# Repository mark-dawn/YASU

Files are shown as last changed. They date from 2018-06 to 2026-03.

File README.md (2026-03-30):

# YASU

## What's this?
__Yet Another Saturn__ to __USB__ is a small pet project with 3 aims:
1. Connect a couple of Saturn controllers to my PC for retrogaming
2. Learn how the USB protocol works
3. Learn how to make a PCB and other hardware shenanigans

While I do not expect it to blow anyone's mind, I believe that the code and board turned out quite good
and are usable both in practice and for learning purposes.

## Hardware support
For now only the standard Saturn controller is supported, and has been tested with Japanese `HSS-0101` controllers.

However the code is structured so it should be easy to add support for other Saturn peripherals;
for sure, support for the _3D Controller_ is planned since I own one of those.

Support for the Saturn Mouse might be harder since the board should reconfigure itself as a pointer HID device at enumeration time.

## Note about contacts
The connection between board and the Saturn plug is handled quite rudimentary at the moment.
Flat naked metal pads on tabs that fit inside the cavity of the plug are present,
but cannot make direct contact with the pads in the plug.

For now the "intended" way is to solder extension metal pads to make contact,
but it is quite hard to solder those manually and the connection can act shaky.

In the future I plan to swap those out for flat pogo pins, or if no suitable part exists, use a proper 3D printed receptacle.

## Credits
This project would have not been as easy as it was without various resources from the Internets.
* Objective development for the excellent [v-usb library](https://github.com/obdev/v-usb)
* [Raphaël Assénat](http://www.raphnet.net/index_en), that has a similar [project](http://www.raphnet.net/electronique/saturn_usb/index_en.php) with excellent documentation
* https://gamesx.com/controldata/saturn.htm for a starting point on how to read the standard controller
* Any kind soul that has written small tutorials for ~~messy sintax~~ makefiles

## TODO
* Fix contact between board and Saturn Plug
* Add support for 3D pad
* Extend credits list, expecially for HID configuration examples
* Look into how licenses work since v-usb is under the GPL-2, and go around and slap it in the files that necessitate it
* Add better documentation to `Saturn.c` to clarify which bits are getting extracted without having to look at the header file

## License
All the repository is licensed under the GPL-3. See `LICENSE` for more info.

    Copyright (C) 2022  Marica Albanesi

    This program is free software: you can redistribute it and/or modify
    it under the terms of the GNU General Public License as published by
    the Free Software Foundation, either version 3 of the License, or
    (at your option) any later version.

    This program is distributed in the hope that it will be useful,
    but WITHOUT ANY WARRANTY; without even the implied warranty of
    MERCHANTABILITY or FITNESS FOR A PARTICULAR PURPOSE.  See the
    GNU General Public License for more details.

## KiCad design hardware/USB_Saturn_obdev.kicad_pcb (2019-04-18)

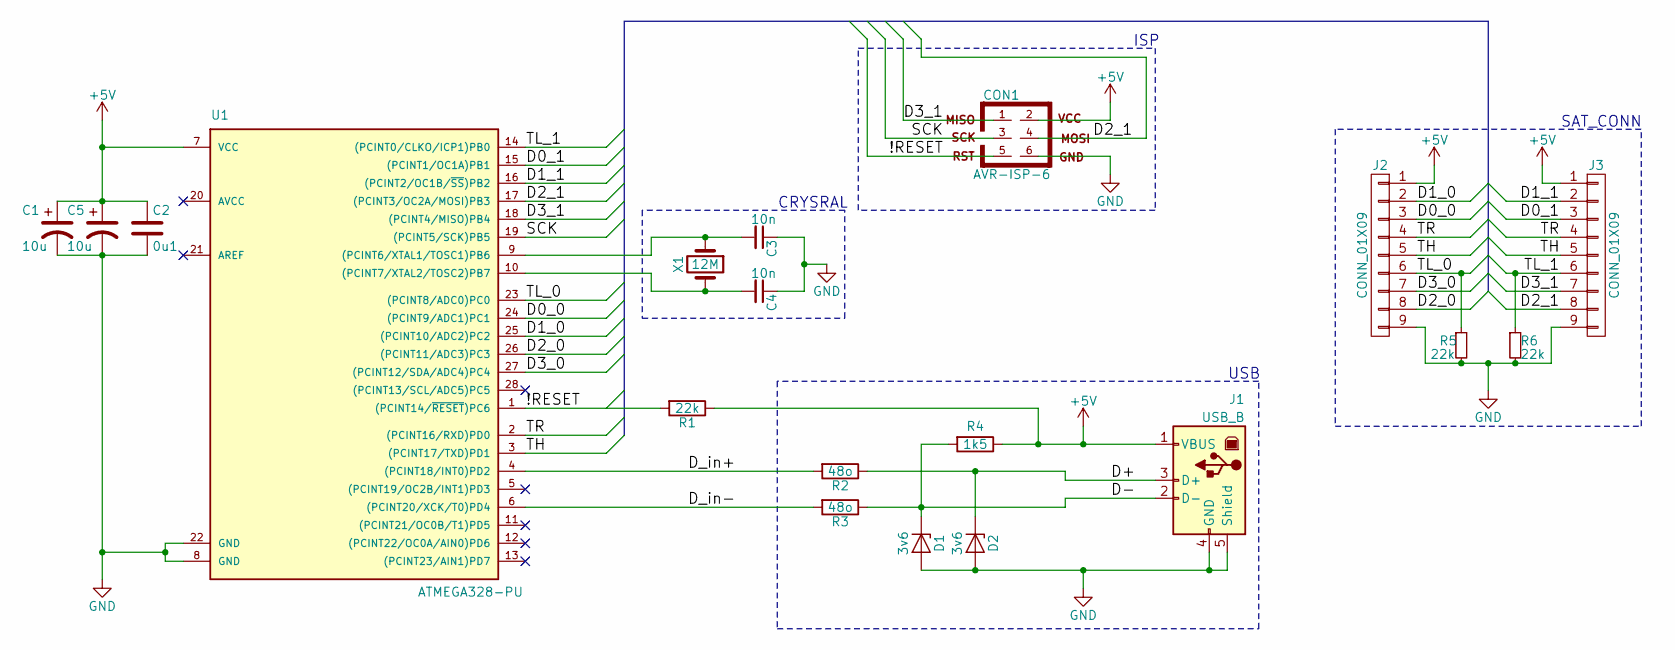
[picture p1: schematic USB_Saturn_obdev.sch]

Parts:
C1, C5: 10u; CP_Radial_D4.0mm_P2.00mm
C2: 0u1; C_Disc_D3.4mm_W2.1mm_P2.50mm
C3, C4: 10n; C_Disc_D3.4mm_W2.1mm_P2.50mm
CON1: AVR-ISP-6; PinHeader_2x03_P2.54mm_Vertical
D1, D2: 3v6; D_T-1_P5.08mm_Horizontal
J1: USB_B; USB_B_OST_USB-B1HSxx_Horizontal
J2, J3: CONN_01X09; Saturn_f_standalone
R1, R5, R6: 22k; R_Axial_DIN0207_L6.3mm_D2.5mm_P10.16mm_Horizontal
R2, R3: 48o; R_Axial_DIN0207_L6.3mm_D2.5mm_P10.16mm_Horizontal
R4: 1k5; R_Axial_DIN0207_L6.3mm_D2.5mm_P10.16mm_Horizontal
U1: ATMEGA328-PU; DIP-28_W7.62mm
X1: 12M; Crystal_HC49-4H_Vertical

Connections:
+5V: C1.1, C2.1, C5.1, CON1.2, J1.1 (VBUS), J2.1, J3.1, R1.1, R4.1, U1.7 (VCC)
/!RESET: CON1.5, R1.2, U1.1 ((PCINT14/~RESET~)PC6)
/D0_0: J2.3, U1.24 ((PCINT9/ADC1)PC1)
/D0_1: J3.3, U1.15 ((PCINT1/OC1A)PB1)
/D1_0: J2.2, U1.25 ((PCINT10/ADC2)PC2)
/D1_1: J3.2, U1.16 ((PCINT2/OC1B/~SS~)PB2)
/D2_0: J2.8, U1.26 ((PCINT11/ADC3)PC3)
/D2_1: CON1.4, J3.8, U1.17 ((PCINT3/OC2A/MOSI)PB3)
/D3_0: J2.7, U1.27 ((PCINT12/SDA/ADC4)PC4)
/D3_1: CON1.1, J3.7, U1.18 ((PCINT4/MISO)PB4)
/D+: D2.1 (K), J1.3 (D+), R2.1
/D-: D1.1 (K), J1.2 (D-), R3.1, R4.2
/D_in+: R2.2, U1.4 ((PCINT18/INT0)PD2)
/D_in-: R3.2, U1.6 ((PCINT20/XCK/T0)PD4)
/SCK: CON1.3, U1.19 ((PCINT5/SCK)PB5)
/TH: J2.5, J3.5, U1.3 ((PCINT17/TXD)PD1)
/TL_0: J2.6, R5.1, U1.23 ((PCINT8/ADC0)PC0)
/TL_1: J3.6, R6.1, U1.14 ((PCINT0/CLKO/ICP1)PB0)
/TR: J2.4, J3.4, U1.2 ((PCINT16/RXD)PD0)
GND: C1.2, C2.2, C3.1, C4.1, C5.2, CON1.6, D1.2 (A), D2.2 (A), J1.4 (GND), J1.5 (Shield), J2.9, J3.9, R5.2, R6.2, U1.8 (GND), U1.22 (GND)
unnamed: C3.2, U1.9 ((PCINT6/XTAL1/TOSC1)PB6), X1.1
unnamed: C4.2, U1.10 ((PCINT7/XTAL2/TOSC2)PB7), X1.2

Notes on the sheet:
USB
ISP
CRYSRAL
SAT_CONN

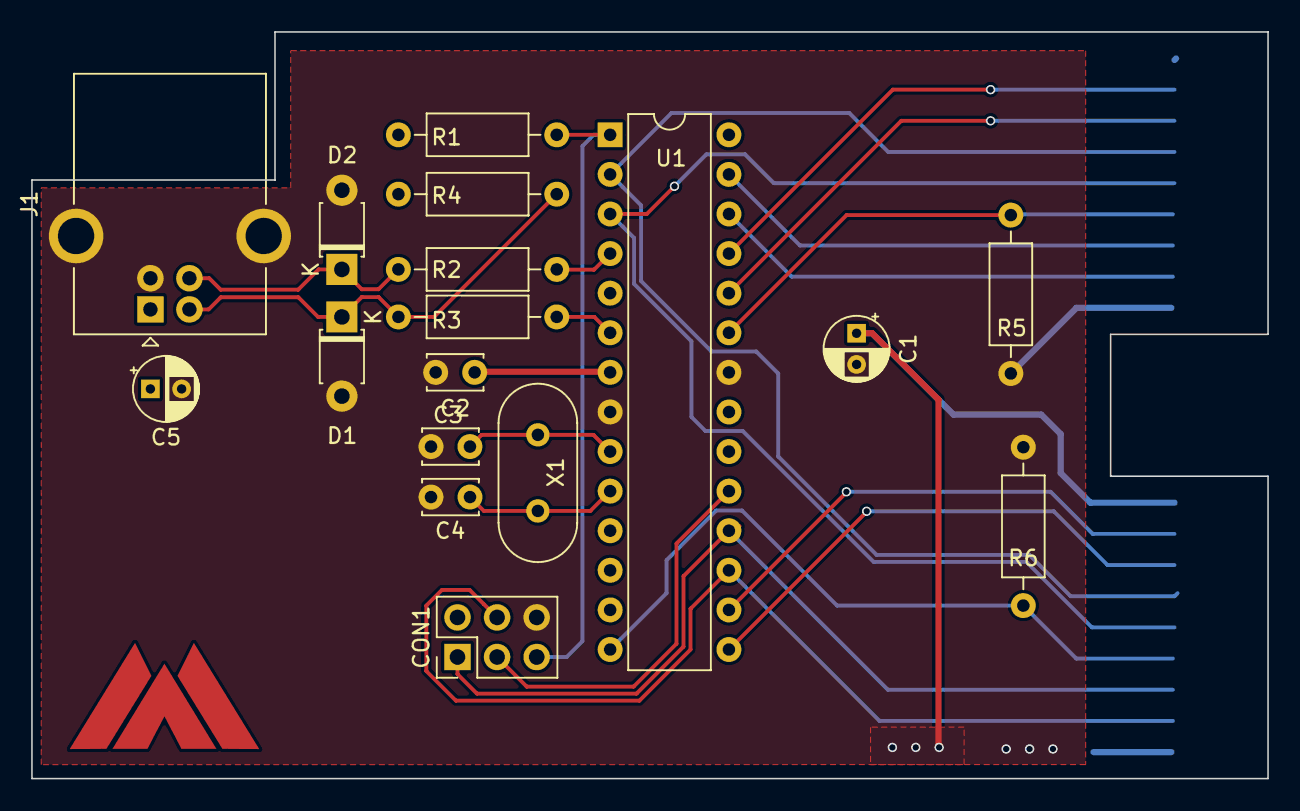
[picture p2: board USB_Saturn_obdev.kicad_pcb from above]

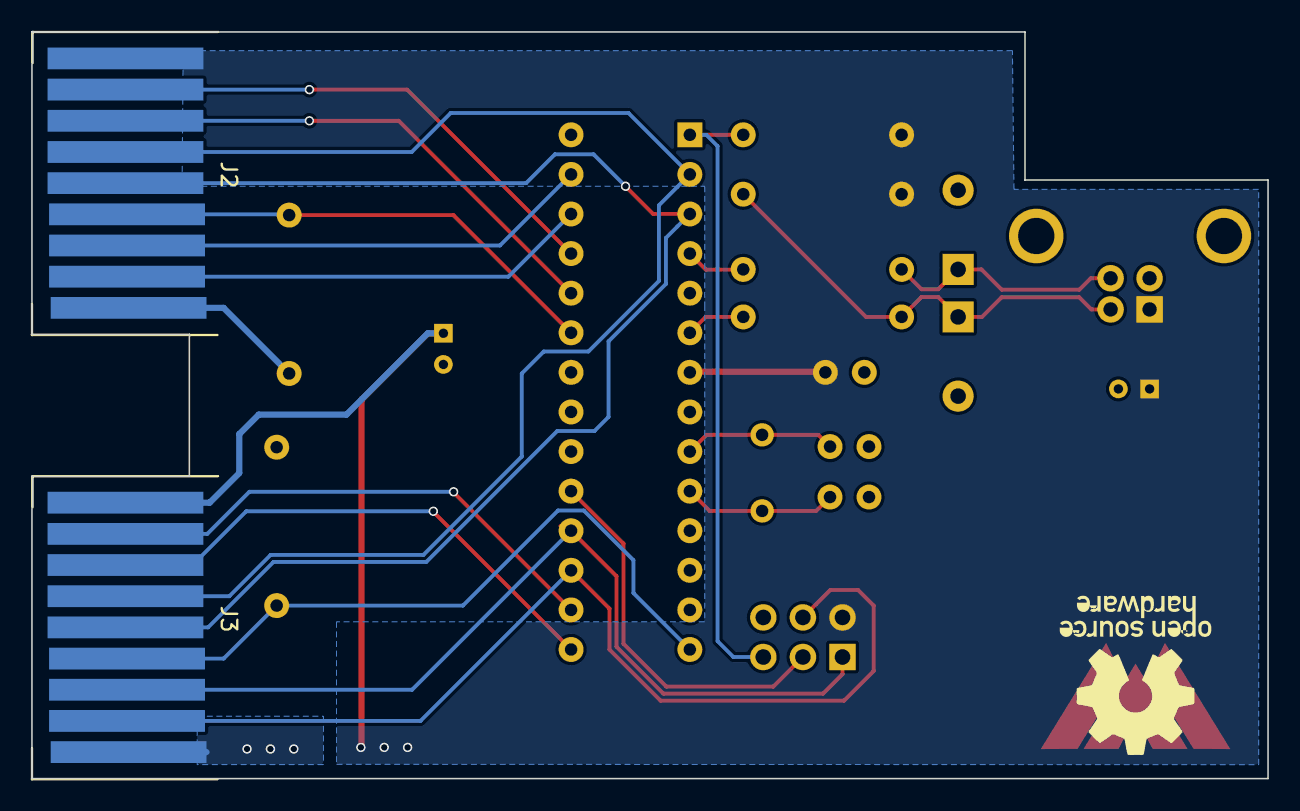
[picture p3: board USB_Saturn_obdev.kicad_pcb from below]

Board: 2 copper layers, 79.3 x 47.9 mm, 21 parts (3 on the bottom side), 22 nets.

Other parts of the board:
logo_MA2: G***; logo_MA2
svg2mod: G***; osh_silk

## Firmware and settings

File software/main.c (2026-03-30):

#include <inttypes.h>
#include <avr/interrupt.h>
#include <util/delay.h>
#include "usbconfig.h"
#include "usbdrv.h"
#include "Saturn.h"
#include "comm.h"

 #define F_CPU 12000000UL

int __attribute__((OS_main)) main(void) {
    cli();
    // variables
    PORTD = 0x00;
    struct sat_controller cntr[2];
    // init routines
    sat_init(cntr);
    comm_init();
    // turn on interrupts
    sei();
    // begin main loop
    while(1){
        _delay_ms(2);
        for(uint8_t i = 0; i<2; i++) {
            if (cntr[i].upd) {cntr[i].upd(cntr[i].state, i);}
        }
        comm_data(cntr[0].state, cntr[1].state);
    }
}

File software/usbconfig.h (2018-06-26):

/* Name: usbconfig.h
 * Project: V-USB, virtual USB port for Atmel's(r) AVR(r) microcontrollers
 * Author: Christian Starkjohann
 * Creation Date: 2005-04-01
 * Tabsize: 4
 * Copyright: (c) 2005 by OBJECTIVE DEVELOPMENT Software GmbH
 * License: GNU GPL v2 (see License.txt), GNU GPL v3 or proprietary (CommercialLicense.txt)
 */

#ifndef __usbconfig_h_included__
#define __usbconfig_h_included__

/*
General Description:
This file is an example configuration (with inline documentation) for the USB
driver. It configures V-USB for USB D+ connected to Port D bit 2 (which is
also hardware interrupt 0 on many devices) and USB D- to Port D bit 4. You may
wire the lines to any other port, as long as D+ is also wired to INT0 (or any
other hardware interrupt, as long as it is the highest level interrupt, see
section at the end of this file).
+ To create your own usbconfig.h file, copy this file to your project's
+ firmware source directory) and rename it to "usbconfig.h".
+ Then edit it accordingly.
*/

/* ---------------------------- Hardware Config ---------------------------- */

#define USB_CFG_IOPORTNAME      D
/* This is the port where the USB bus is connected. When you configure it to
 * "B", the registers PORTB, PINB and DDRB will be used.
 */
#define USB_CFG_DMINUS_BIT      4
/* This is the bit number in USB_CFG_IOPORT where the USB D- line is connected.
 * This may be any bit in the port.
 */
#define USB_CFG_DPLUS_BIT       2
/* This is the bit number in USB_CFG_IOPORT where the USB D+ line is connected.
 * This may be any bit in the port. Please note that D+ must also be connected
 * to interrupt pin INT0! [You can also use other interrupts, see section
 * "Optional MCU Description" below, or you can connect D- to the interrupt, as
 * it is required if you use the USB_COUNT_SOF feature. If you use D- for the
 * interrupt, the USB interrupt will also be triggered at Start-Of-Frame
 * markers every millisecond.]
 */
#define USB_CFG_CLOCK_KHZ       (F_CPU/1000)
/* Clock rate of the AVR in kHz. Legal values are 12000, 12800, 15000, 16000,
 * 16500, 18000 and 20000. The 12.8 MHz and 16.5 MHz versions of the code
 * require no crystal, they tolerate +/- 1% deviation from the nominal
 * frequency. All other rates require a precision of 2000 ppm and thus a
 * crystal!
 * Since F_CPU should be defined to your actual clock rate anyway, you should
 * not need to modify this setting.
 */
#define USB_CFG_CHECK_CRC       0
/* Define this to 1 if you want that the driver checks integrity of incoming
 * data packets (CRC checks). CRC checks cost quite a bit of code size and are
 * currently only available for 18 MHz crystal clock. You must choose
 * USB_CFG_CLOCK_KHZ = 18000 if you enable this option.
 */

/* ----------------------- Optional Hardware Config ------------------------ */

/* #define USB_CFG_PULLUP_IOPORTNAME   D */
/* If you connect the 1.5k pullup resistor from D- to a port pin instead of
 * V+, you can connect and disconnect the device from firmware by calling
 * the macros usbDeviceConnect() and usbDeviceDisconnect() (see usbdrv.h).
 * This constant defines the port on which the pullup resistor is connected.
 */
/* #define USB_CFG_PULLUP_BIT          4 */
/* This constant defines the bit number in USB_CFG_PULLUP_IOPORT (defined
 * above) where the 1.5k pullup resistor is connected. See description
 * above for details.
 */

/* --------------------------- Functional Range ---------------------------- */
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

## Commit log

2018-06-26 Initial commit
    Most of the project is in a working state
    [USB_Saturn_obdev.kicad_pcb, USB_Saturn_obdev.sch, USB_Saturn_obdev_flat_USB.kicad_pcb]
2018-07-14 Added backup library
    Changed logos
    [USB_Saturn_obdev.kicad_pcb, USB_Saturn_obdev.sch]
2019-04-18 Kicad format changes
    [USB_Saturn_obdev.kicad_pcb, USB_Saturn_obdev.sch]
